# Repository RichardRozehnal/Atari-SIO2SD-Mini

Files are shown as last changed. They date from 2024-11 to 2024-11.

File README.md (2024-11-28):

# Atari SIO2SD Mini

Atari SIO2SD Mini je zařízení, které vám umožní nahrávat programy a hry do Atari přes SIO konektor z MicroSD karty.
Podporuje soubory ATR, XEX, COM a XFD.

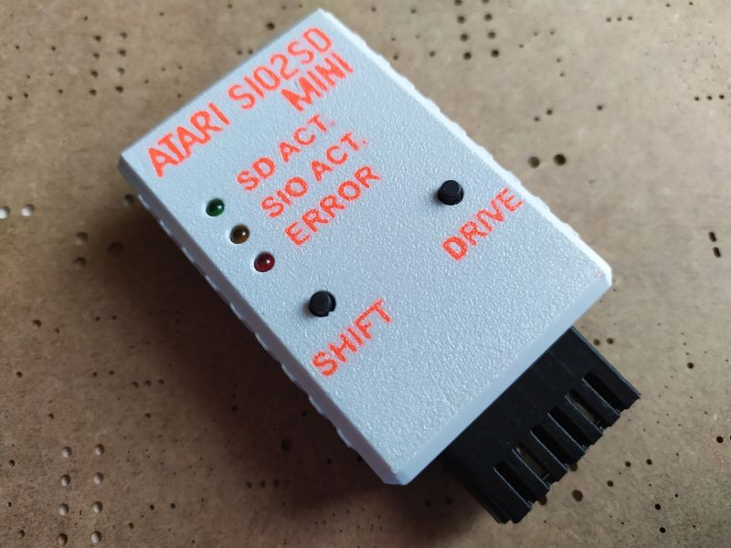
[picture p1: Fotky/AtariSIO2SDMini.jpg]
Atari SIO2SD Mini

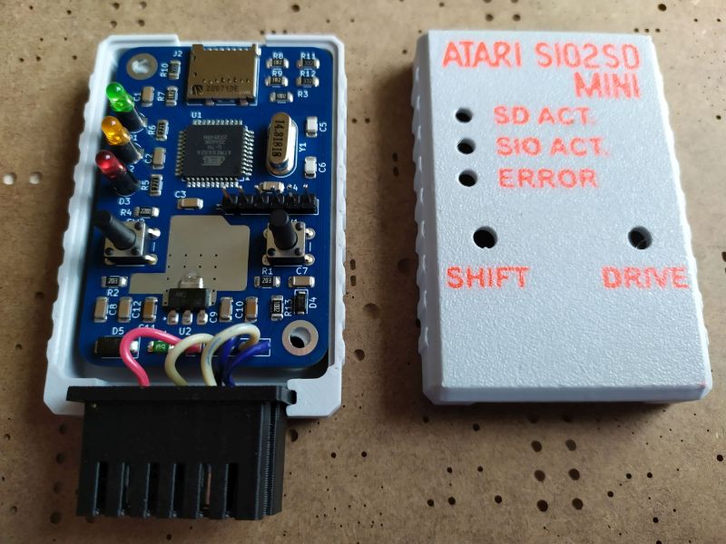
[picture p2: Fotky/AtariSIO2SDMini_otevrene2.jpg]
Atari SIO2SD Mini otevřené

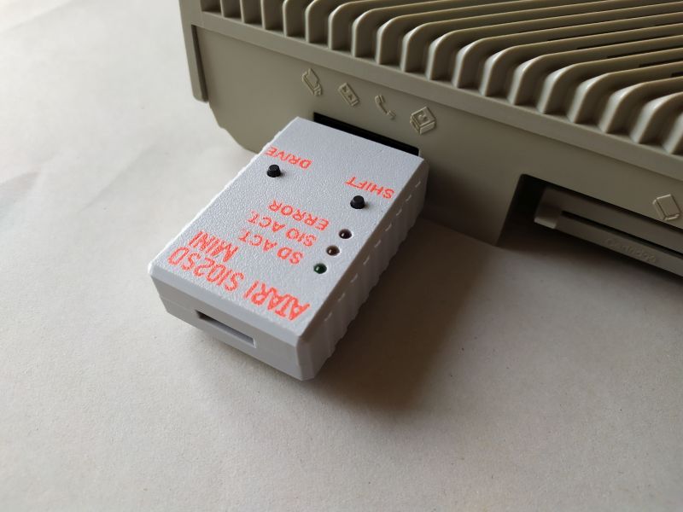
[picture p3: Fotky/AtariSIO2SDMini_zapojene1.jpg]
Atari SIO2SD Mini zapojené


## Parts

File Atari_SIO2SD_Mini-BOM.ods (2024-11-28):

Atari SIO2SD Mini – BOM
Reference | Qty | Value | Footprint | Description
C1,C2,C3,C4,C7,C8,C9,C12 | 8 | 100nF | Atari_SIO2SD_Mini:C_1206_3216Metric | Unpolarized capacitor
C5,C6 | 2 | 22pF | Atari_SIO2SD_Mini:C_1206_3216Metric | Unpolarized capacitor
C10,C11 | 2 | 10uF | Atari_SIO2SD_Mini:C_1206_3216Metric | Unpolarized capacitor
D1 | 1 | Green | Atari_SIO2SD_Mini:LED_D3.0mm | Light emitting diode
D2 | 1 | Yellow | Atari_SIO2SD_Mini:LED_D3.0mm | Light emitting diode
D3 | 1 | Red | Atari_SIO2SD_Mini:LED_D3.0mm | Light emitting diode
D4 | 1 | SKL16 | Atari_SIO2SD_Mini:D_SOD-123F | Schottky diode
D5 | 1 | P4SMAJ5.0A | Atari_SIO2SD_Mini:D_SMA | 400W unidirectional Transient Voltage Suppressor, 5.0Vr, SMA(DO-214AC)
F1 | 1 | SN050-08 | Atari_SIO2SD_Mini:Fuse_1206_3216Metric | Resettable fuse, polymeric positive temperature coefficient
J1 | 1 | Programming Connector | Atari_SIO2SD_Mini:PinHeader_1x06_P2.54mm_Vertical | Generic connector, single row, 01x06, script generated (kicad-library-utils/schlib/autogen/connector/)
J2 | 1 | Micro_SD_Card | Atari_SIO2SD_Mini:microSD_HC_Molex_104031-0811 | Micro SD Card Socket
J3 | 1 | SIO Pads | Atari_SIO2SD_Mini:PinHeader_1x05_P2.54mm_Vertical | Generic connector, single row, 01x05, script generated (kicad-library-utils/schlib/autogen/connector/)
R1,R2 | 2 | 20K | Atari_SIO2SD_Mini:R_1206_3216Metric | Resistor
R3,R13 | 2 | 10K | Atari_SIO2SD_Mini:R_1206_3216Metric | Resistor
R4,R5,R6 | 3 | 220R | Atari_SIO2SD_Mini:R_1206_3216Metric | Resistor
R7,R8,R9 | 3 | 1K8 | Atari_SIO2SD_Mini:R_1206_3216Metric | Resistor
R10,R11,R12 | 3 | 3K3 | Atari_SIO2SD_Mini:R_1206_3216Metric | Resistor
SW1 | 1 | K1 (DRIVE) | Atari_SIO2SD_Mini:SW_PUSH_6mm_H12mm | Push button switch, generic, two pins
SW2 | 1 | K5 (SHIFT) | Atari_SIO2SD_Mini:SW_PUSH_6mm_H12mm | Push button switch, generic, two pins
U1 | 1 | ATmega32A-A | Atari_SIO2SD_Mini:TQFP-44_10x10mm_P0.8mm | 16MHz, 32kB Flash, 2kB SRAM, 1kB EEPROM, JTAG, TQFP-44
U2 | 1 | AMS1117-3.3 | Atari_SIO2SD_Mini:SOT-223-3_TabPin2 | 1A Low Dropout regulator, positive, 3.3V fixed output, SOT-223
Y1 | 1 | 14.31818MHz | Atari_SIO2SD_Mini:Crystal_HC49-4H_Vertical | Two pin crystal
 | 5 | Molex 08-50-0106 |  | kontakty do SIO konektoru
 | 1 | krabička
 | 2 | samořezky 3mm/9,5mm

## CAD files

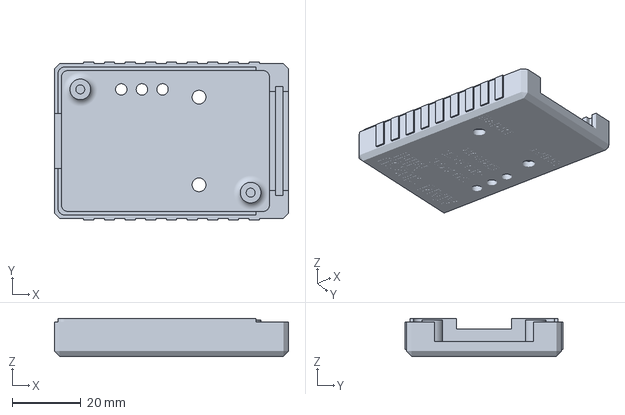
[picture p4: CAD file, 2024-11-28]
Atari_SIO2SD_Mini_Enclosure/Atari_SIO2SD_Mini_Enclosure_Top.3mf
68.0 x 46.0 x 11.0 mm

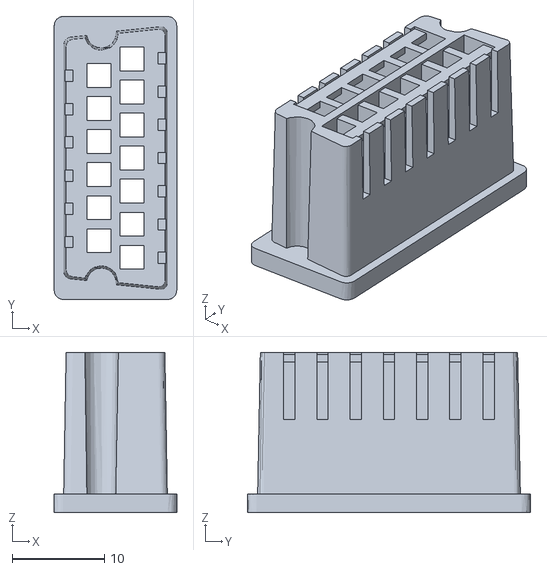
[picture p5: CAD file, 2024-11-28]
Atari_SIO2SD_Mini_Enclosure/Atari_SIO2SD_Mini_Connector_Plug.stl
13.3 x 30.7 x 17.4

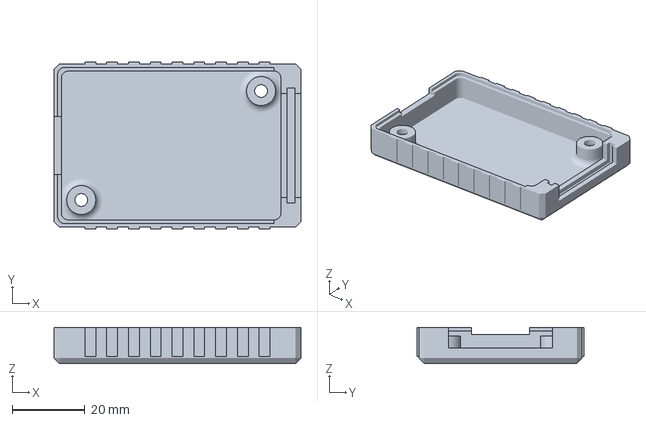
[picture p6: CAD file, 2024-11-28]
Atari_SIO2SD_Mini_Enclosure/Atari_SIO2SD_Mini_Enclosure_Bot.3mf
68.0 x 46.0 x 10.0 mm

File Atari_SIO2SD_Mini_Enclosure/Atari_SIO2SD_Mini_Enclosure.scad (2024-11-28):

//-----------------------------//
// Atari SIO2SD Mini Enclosure //
//        Richi 10.2024        //
//-----------------------------//

include <BOSL2/std.scad>
use <SF Atarian System.ttf>

$fn = 256;
DPSx = 58.50;
DPSy = 39;
spodni = 0;

if (spodni == 1){
    diff(){
        // dno krabičky
        move([1.75, 0, 0]) cuboid([DPSx + 2 + 3.5 + 4, DPSy + 2 + 4, 2], chamfer = 1.5, edges = [BACK+LEFT, LEFT+FRONT, FRONT+    RIGHT, RIGHT+BACK, BOT], anchor = BOTTOM){

            // podpěry na DPS, spodní strana krabičky
            move([-26.5, -15, 0]) attach (TOP, BOT) cyl(d = 8, l = 5.6, rounding1 = -2){
                tag("remove") cyl(d = 3.5, l = 9.6, rounding = 0);
                tag("remove") move([0, 0, -1.8]) cyl(d = 5.7, l = 6, rounding1 = -1, rounding2 = 1);
        
            move([49.5, 30, 0]) cyl(d = 8, l = 5.6, rounding1 = -2){
                tag("remove") cyl(d = 3.5, l = 9.6, rounding = 0);
                tag("remove") move([0, 0, -1.8]) cyl(d = 5.7, l = 6, rounding1 = -1, rounding2 = 1);
            }        
            }
        } 

    // stěny krabičky
    move([0, 0, 2]) rect_tube(isize = [DPSx + 2, DPSy + 2], wall = 2, h = 7.15 + 0.85, chamfer = ([0, 1.5, 1.5, 0]), irounding = ([2, 2, 2, 2])) 

    // rozšíření stěny na konektor
    move([34, 0, 0]) cuboid([3.5, 30.7 + 14.3, 7.15 + 0.85], chamfer = 1.5, edges = [FRONT+RIGHT, RIGHT+BACK]);

    // drážka na konektor
    tag("remove") move([33, 0, 2 + 0.85]) cuboid([2.2, 30.7 + 1, 10], anchor = BOTTOM); 

    // otvor na konektor
    tag("remove") move([33, 0,3.50 + 0.85]) cuboid([6.5, 30.7 + 1 - 3, 10], anchor = BOTTOM); 

    // podélná drážka okolo krabičky, spodní
    tag("remove") move([-1.5, 0, 9]) rect_tube(isize = [DPSx - 3, DPSy], wall = 2, h = 2, rounding = ([0, 2, 2, 0]));
   
    // výřez pro MicroSD kartu
    tag("remove") move([-31.25, 0, 2 + 2 + 6]) cuboid([4, 16, 4]);     
    
    }

    // drážky po stranách
    ycopies(45.5) move([1.75, 0, 6]) cuboid([3, 0.5, 8]);
    xcopies(12) ycopies(45.5) move([1.75, 0, 6]) cuboid([3, 0.5, 8]);
    xcopies(24) ycopies(45.5) move([1.75, 0, 6]) cuboid([3, 0.5, 8]);
    xcopies(36) ycopies(45.5) move([1.75, 0, 6]) cuboid([3, 0.5, 8]);
    xcopies(48) ycopies(45.5) move([1.75, 0, 6]) cuboid([3, 0.5, 8]);
}

else {
    diff(){
        // dno krabičky
        move([1.75, 0, 0]) cuboid([DPSx + 2 + 3.5 + 4, DPSy + 2 + 4, 2], chamfer = 1.5, edges = [BACK+LEFT, LEFT+FRONT, FRONT+RIGHT, RIGHT+BACK, BOT], anchor = BOTTOM){
    
            // podpěry na DPS, vrchní strana krabičky
            move([-26.5, 15, 0]) attach (TOP, BOT) cyl(d = 6, l = 8.6, rounding1 = -2){
                move([0, 0, 0.5]) tag("remove") cyl(d = 2.6, l = 9.6);  // otvor na samořezku 3mm/9.5mm
        
            move([49.5, -30, 0]) cyl(d = 6, l = 8.6, rounding1 = -2){
                move([0, 0, 0.5]) tag("remove") cyl(d = 2.6, l = 9.6);  // otvor na samořezku 3mm/9.5mm
            }       
            }
            
            // otvory pro 3mm LEDky
            tag("remove") move([-14.6, 15, 0]) cyl(d = 3.3, 4);
            tag("remove") move([-14.6 + 6, 15, 0]) cyl(d = 3.3, 4);
            tag("remove") move([-14.6 + 6 + 6, 15, 0]) cyl(d = 3.3, 4);
    
            // otvory pro tlačítka
            tag("remove") move([-31 + 39, 19.5 - 6.75, 0]) cyl(d = 4, 4);
            tag("remove") move([-31 + 39, -19.5 + 6.75, 0]) cyl(d = 4, 4);
    
            // texty
            move([-27.2, 0, -0.55]) rot([180, 0, -90]) color ("red") linear_extrude(height = 0.5) text("ATARI SIO2SD", size = 6, font ="SF Atarian System", anchor=CENTER);
            move([-21, -11, -0.55]) rot([180, 0, -90]) color ("red") linear_extrude(height = 0.5) text("MINI", size = 6, font ="SF Atarian System", anchor=CENTER);
    
            move([-14.6, 10, -0.55]) rot([180, 0, -90]) color ("red") linear_extrude(height = 0.5) text("SD ACT.", size = 3.4, font ="Arial:style=Bold", anchor=LEFT);
            move([-8.6, 10, -0.55]) rot([180, 0, -90]) color ("red") linear_extrude(height = 0.5) text("SIO ACT.", size = 3.4, font ="Arial:style=Bold", anchor=LEFT);
            move([-2.6, 10, -0.55]) rot([180, 0, -90]) color ("red") linear_extrude(height = 0.5) text("ERROR", size = 3.4, font ="Arial:style=Bold", anchor=LEFT);
            move([14.8, 12.75, -0.55]) rot([180, 0, -90]) color ("red") linear_extrude(height = 0.5) text("SHIFT", size = 3.4, font ="Arial:style=Bold", anchor=CENTER);
            move([14.8, -12.75, -0.55]) rot([180, 0, -90]) color ("red") linear_extrude(height = 0.5) text("DRIVE", size = 3.4, font ="Arial:style=Bold", anchor=CENTER);
        }        
    }

    diff(){   
        // stěny krabičky
        move([0, 0, 2]) rect_tube(isize = [DPSx + 2, DPSy + 2], wall = 2, h = 7.15 + 0.85 + 1, chamfer = ([0, 1.5, 1.5, 0]), irounding = ([2, 2, 2, 2])) 

        // rozšíření stěny na konektor
        move([34, 0, 0]) cuboid([3.5, 30.7 + 14.3, 7.15 + 0.85 + 1], chamfer = 1.5, edges = [FRONT+RIGHT, RIGHT+BACK]);

        // drážka na konektor
        tag("remove") move([33, 0, 2 + 0.85]) cuboid([2.2, 30.7 + 1, 10], anchor = BOTTOM); 

        // otvor na konektor
        tag("remove") move([33, 0, 3.50 + 0.85]) cuboid([6.5, 30.7 + 1 - 3, 10], anchor = BOTTOM); 

        // podélná drážka okolo krabičky, vrchní
        tag("remove") move([-2.5, 0, 10]) rect_tube(isize = [DPSx - 1, DPSy + 4], wall = 2, h = 2, rounding = ([0, 2, 2, 0]), irounding = ([0, 2, 2, 0]));
        tag("remove") move([32, 0, 10]) cuboid([9, 46, 2], anchor = BOTTOM);
    
       // výřez pro MicroSD kartu
       tag("remove") move([-31.25, 0, 2 + 2 + 6]) cuboid([4, 16, 4]);     
    }
    
    // drážky po stranách
    ycopies(45.5) move([1.75, 0, 6]) cuboid([3, 0.5, 8]);
    xcopies(12) ycopies(45.5) move([1.75, 0, 6]) cuboid([3, 0.5, 8]);
    xcopies(24) ycopies(45.5) move([1.75, 0, 6]) cuboid([3, 0.5, 8]);
    xcopies(36) ycopies(45.5) move([1.75, 0, 6]) cuboid([3, 0.5, 8]);
    xcopies(48) ycopies(45.5) move([1.75, 0, 6]) cuboid([3, 0.5, 8]);
}

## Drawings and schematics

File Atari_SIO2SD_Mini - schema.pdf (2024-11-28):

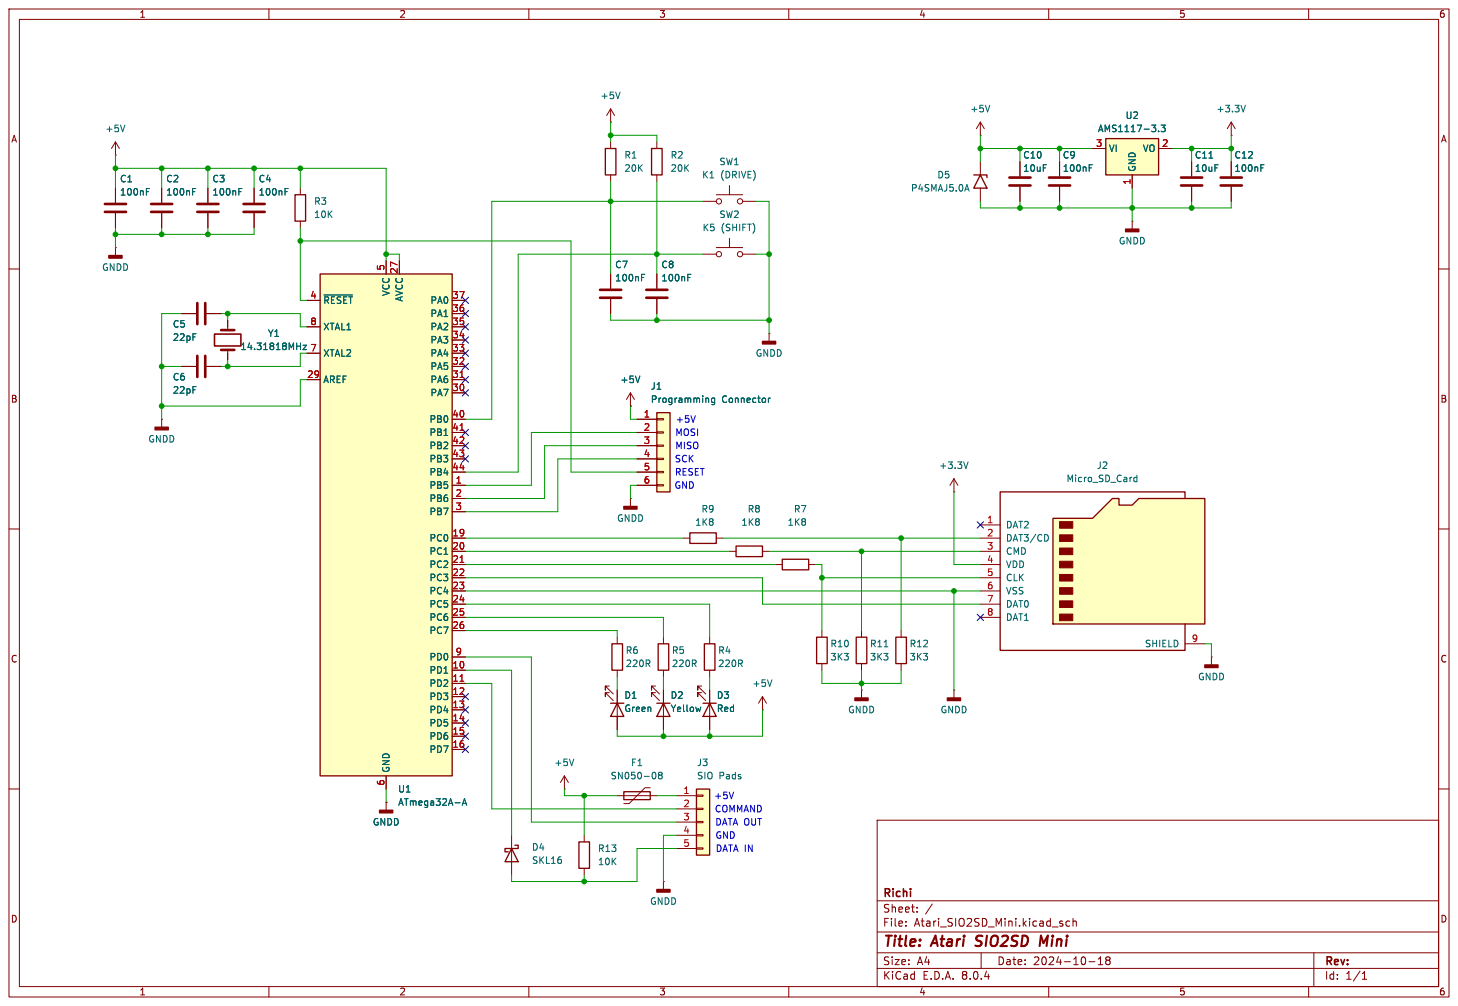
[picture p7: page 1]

Id: 1/1 Title: Atari SIO2SD Mini File: Atari_SIO2SD_Mini.kicad_sch Sheet: / Richi 123456

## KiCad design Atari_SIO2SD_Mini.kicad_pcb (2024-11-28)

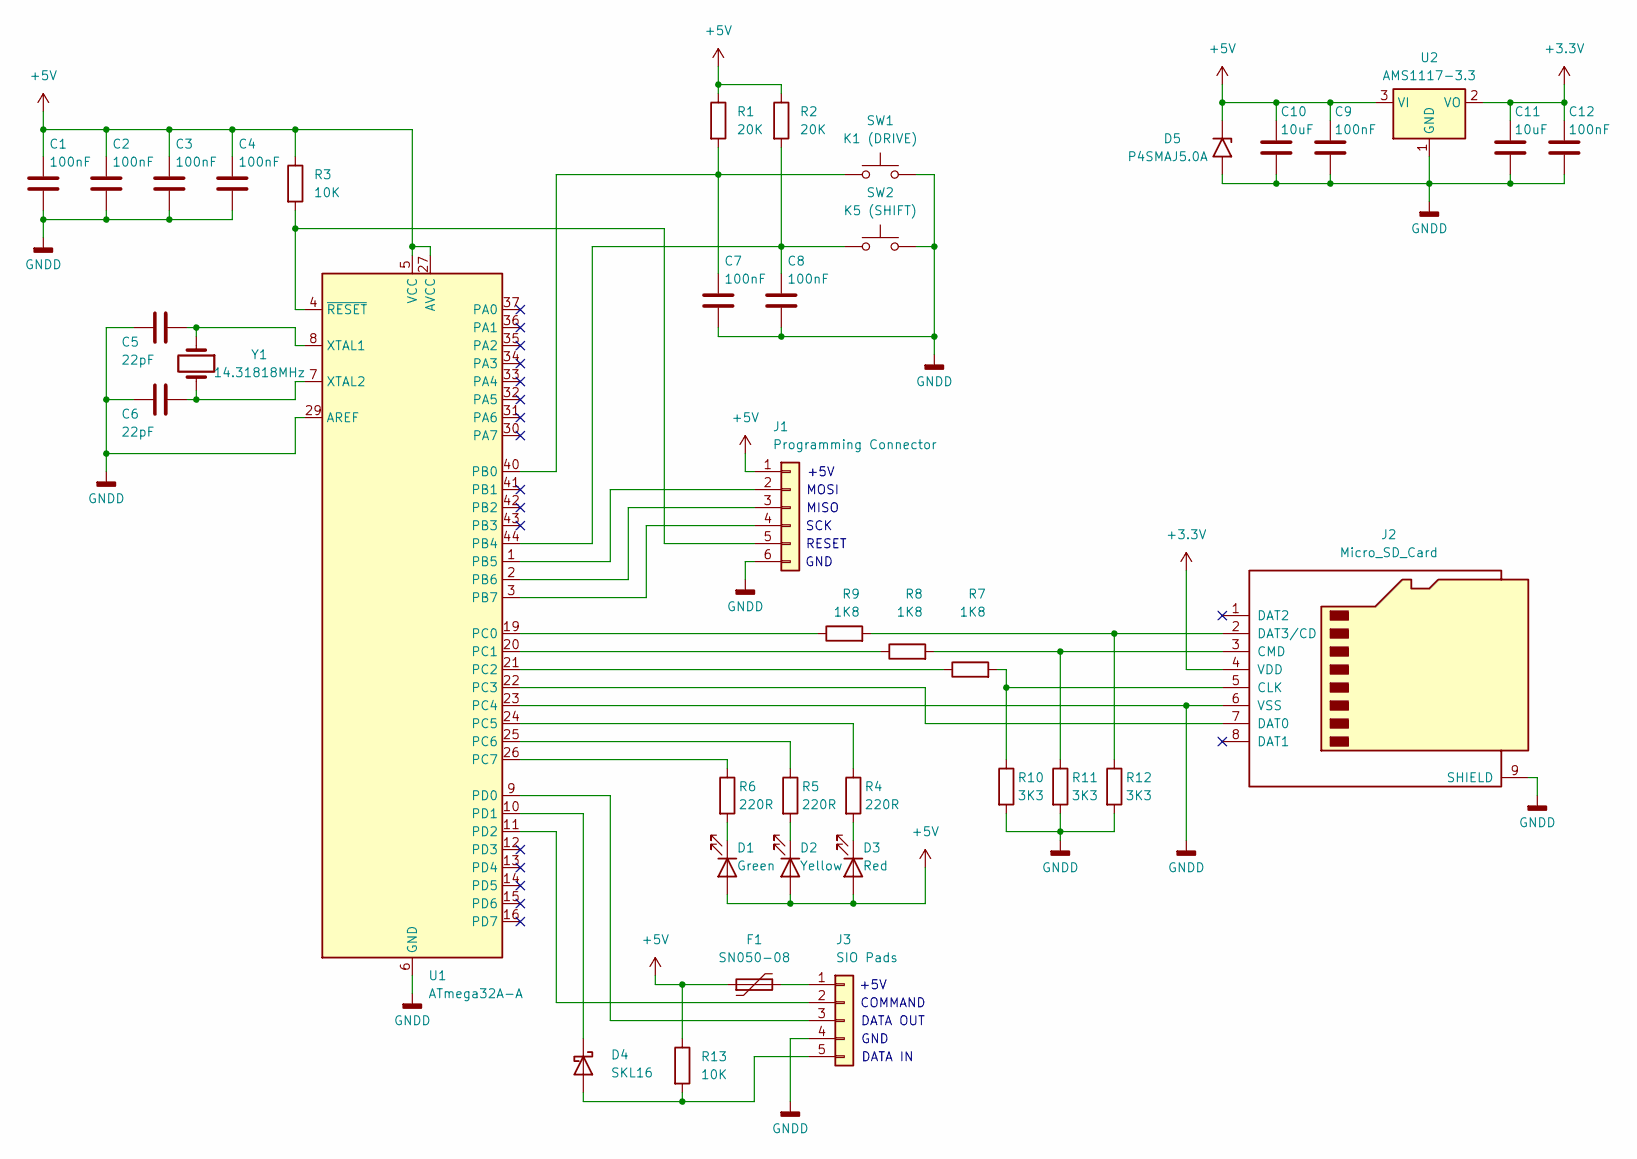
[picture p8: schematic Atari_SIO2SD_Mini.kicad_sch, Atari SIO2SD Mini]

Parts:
C1, C2, C3, C4, C7, C8, C9, C12: 100nF; C_1206_3216Metric
C5, C6: 22pF; C_1206_3216Metric
C10, C11: 10uF; C_1206_3216Metric
D1: Green; LED_D3.0mm
D2: Yellow; LED_D3.0mm
D3: Red; LED_D3.0mm
D4: SKL16; D_SOD-123F
D5: P4SMAJ5.0A; D_SMA
F1: SN050-08; Fuse_1206_3216Metric
J1: Programming Connector; PinHeader_1x06_P2.54mm_Vertical
J2: Micro_SD_Card; microSD_HC_Molex_104031-0811
J3: SIO Pads; PinHeader_1x05_P2.54mm_Vertical
R1, R2: 20K; R_1206_3216Metric
R3, R13: 10K; R_1206_3216Metric
R4, R5, R6: 220R; R_1206_3216Metric
R7, R8, R9: 1K8; R_1206_3216Metric
R10, R11, R12: 3K3; R_1206_3216Metric
SW1: K1 (DRIVE); SW_PUSH_6mm_H12mm
SW2: K5 (SHIFT); SW_PUSH_6mm_H12mm
U1: ATmega32A-A; TQFP-44_10x10mm_P0.8mm
U2: AMS1117-3.3; SOT-223-3_TabPin2
Y1: 14.31818MHz; Crystal_HC49-4H_Vertical

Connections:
+3.3V: C11.1, C12.1, J2.4 (VDD), U2.2 (VO)
+5V: C1.1, C2.1, C3.1, C4.1, C9.1, C10.1, D1.2 (A), D2.2 (A), D3.2 (A), D5.1 (A1), F1.1, J1.1, R1.1, R2.1, R3.1, R13.1, U1.5 (VCC), U1.17 (VCC), U1.27 (AVCC), U1.38 (VCC), U2.3 (VI)
GNDD: C1.2, C2.2, C3.2, C4.2, C5.2, C6.2, C7.2, C8.2, C9.2, C10.2, C11.2, C12.2, D5.2 (A2), J1.6, J2.6 (VSS), J2.9 (SHIELD), J3.4, R10.2, R11.2, R12.2, SW1.2, SW2.2, U1.6 (GND), U1.18 (GND), U1.23 (PC4), U1.28 (GND), U1.29 (AREF), U1.39 (GND), U2.1 (GND)
unnamed: D1.1 (K), R6.2
unnamed: D2.1 (K), R5.2
unnamed: D3.1 (K), R4.2
unnamed: D4.2 (A), J3.5, R13.2
unnamed: D4.1 (K), U1.10 (PD1)
unnamed: J1.2, U1.1 (PB5)
unnamed: J1.3, U1.2 (PB6)
unnamed: J1.4, U1.3 (PB7)
unnamed: J1.5, R3.2, U1.4 (~RESET)
unnamed: J2.5 (CLK), R7.2, R10.1
unnamed: J2.3 (CMD), R8.2, R11.1
unnamed: J2.7 (DAT0), U1.22 (PC3)
unnamed: J2.2 (DAT3/CD), R9.2, R12.1
unnamed: F1.2, J3.1
unnamed: J3.2, U1.11 (PD2)
unnamed: J3.3, U1.9 (PD0)
unnamed: C7.1, R1.2, SW1.1, U1.40 (PB0)
unnamed: C8.1, R2.2, SW2.1, U1.44 (PB4)
unnamed: R9.1, U1.19 (PC0)
unnamed: R8.1, U1.20 (PC1)
unnamed: R7.1, U1.21 (PC2)
unnamed: R4.1, U1.24 (PC5)
unnamed: R5.1, U1.25 (PC6)
unnamed: R6.1, U1.26 (PC7)
unnamed: C5.1, U1.8 (XTAL1), Y1.1
unnamed: C6.1, U1.7 (XTAL2), Y1.2

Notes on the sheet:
+5V
GND
RESET
MOSI
MISO
DATA OUT
DATA IN
COMMAND
+5V
SCK

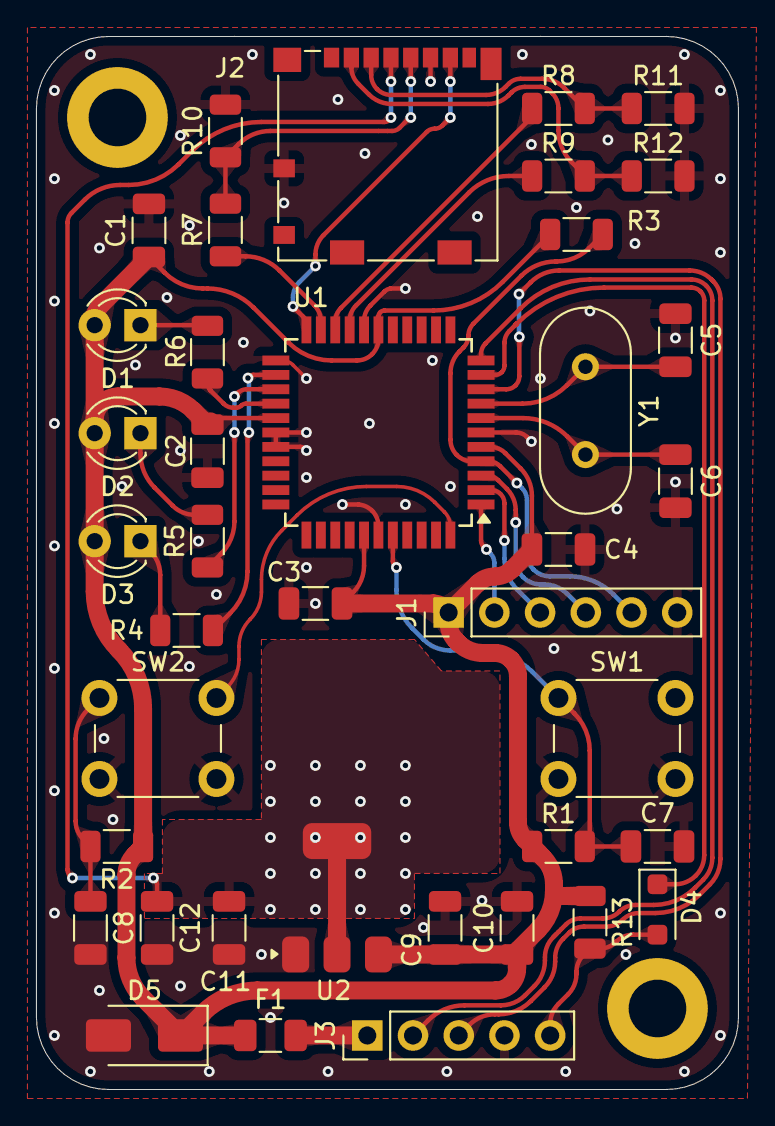
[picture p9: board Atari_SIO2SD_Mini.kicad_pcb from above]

Board: 2 copper layers, 39.0 x 58.5 mm, 39 parts (0 on the bottom side), 29 nets.
